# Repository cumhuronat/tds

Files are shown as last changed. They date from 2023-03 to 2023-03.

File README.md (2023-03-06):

# ESPHome TDS Sensor 
This is a tds sensor based on esp32-pico-d4 to be used for analyzing the status of a water purifier filters.
## Features

 - Powered by esphome
 - AC current generator to prevent polorization
 - OLED screen
 - Production ready
 - ADS1115 for precise voltage readings.
 - Temperature sensor for accurate tds calculation
 - 2.4GHZ PCB Antenna

## Pictures

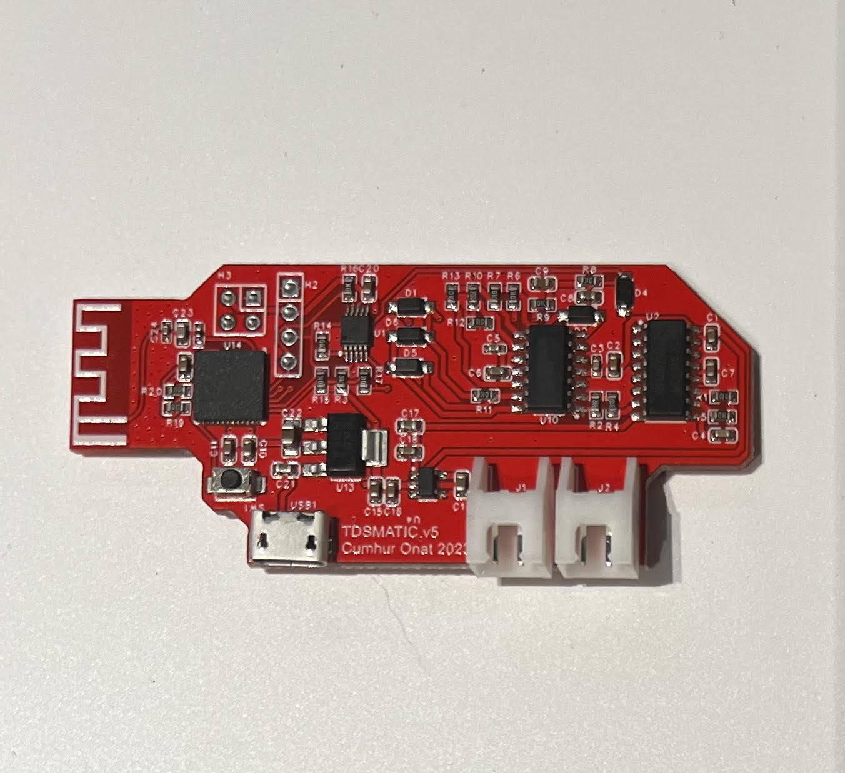
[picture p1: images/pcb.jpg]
pcb


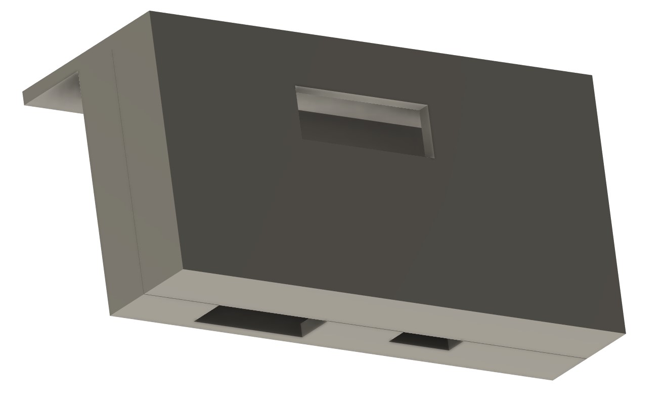
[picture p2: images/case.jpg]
case


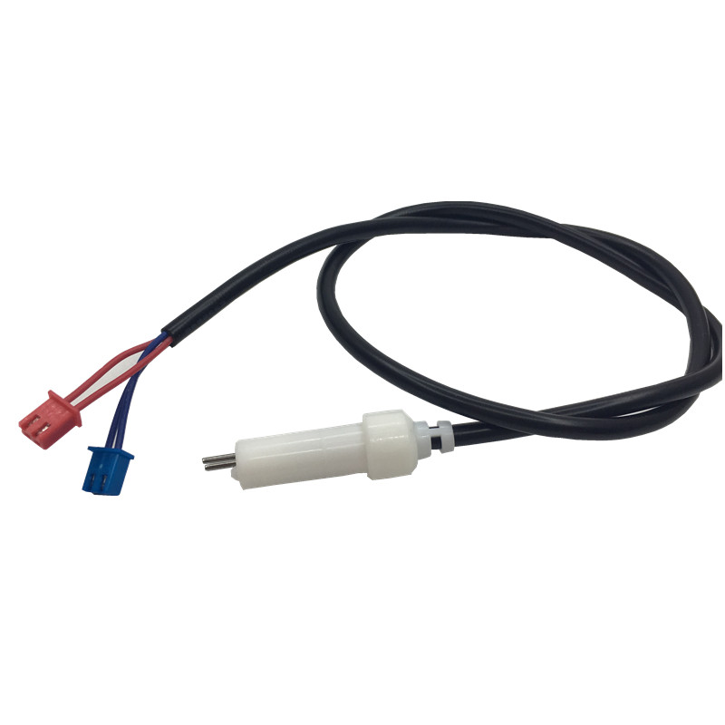
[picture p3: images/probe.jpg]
probe


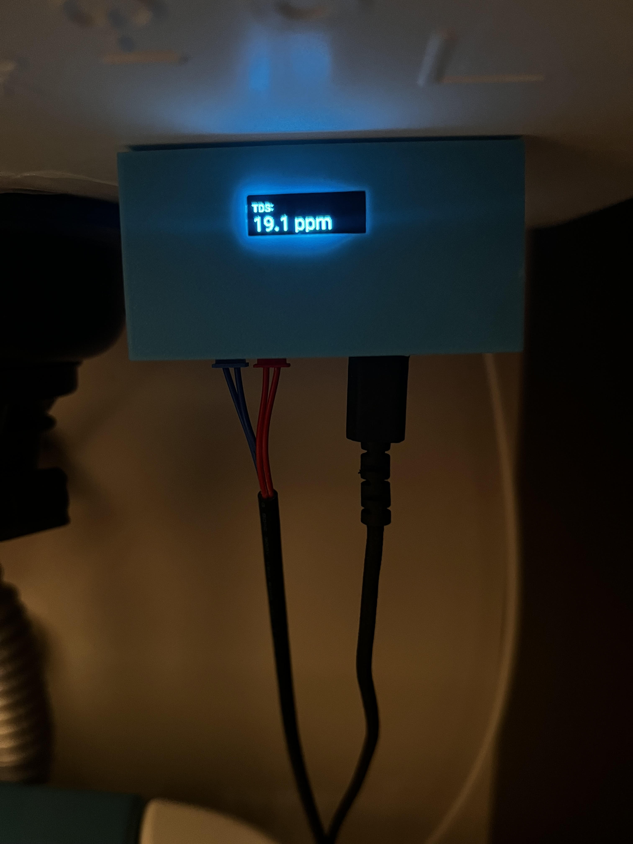
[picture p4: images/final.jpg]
final


## Notes

The pcb doesn't include a usb-ttl module hence you will need an external programmer like USB - TTL UART CP2102 or similar. H2 Header has the necessary pins for this purpose (3V3 GND RX TX).

You will need to order a probe with NTC 10k + electrodes. I've used:
https://www.aliexpress.com/item/1005004315383393.html

Part of the schmatic design is based on:
https://wiki.dfrobot.com/Gravity__Analog_TDS_Sensor___Meter_For_Arduino_SKU__SEN0244

The pcb includes headers for an 128x32 oled screen. I've used the following screen but you can use any oled screen with the same pinout.
https://www.aliexpress.com/item/1005004900370420.html

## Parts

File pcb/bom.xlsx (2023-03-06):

No. | Quantity | Comment | Designator | Footprint | Value | Manufacturer Part | Manufacturer | Supplier Part | Supplier
1 | 8 | 100nF | C1,C2,C6,C7,C11,C12,C16,C18 | C0603 | 100nF | CC0603KRX7R9BB104 | YAGEO(国巨) | C14663 | LCSC
2 | 2 | 4.7uF | C3,C5 | C0402 | 4.7uF | CL05A475MP5NRNC | SAMSUNG(三星) | C23733 | LCSC
3 | 1 | 1nF | C4 | C0603 | 1nF | CL10B102KB8NNNC | SAMSUNG(三星) | C1588 | LCSC
4 | 3 | 1uF | C8,C9,C20 | C0603 | 1uF | CL10A105KB8NNNC | SAMSUNG(三星) | C15849 | LCSC
5 | 5 | 10uF | C10,C14,C15,C17,C21 | C0603 | 10uF | CL10A106KP8NNNC | SAMSUNG(三星) | C19702 | LCSC
6 | 1 | 47uF | C22 | C0805 | 47uF | CL21A476MQYNNNE | SAMSUNG(三星) | C16780 | LCSC
7 | 1 | 4.7pF | C23 | C0603 | 4.7pF | 0603CG4R7C500NT | FH(风华) | C1669 | LCSC
8 | 1 | 2.7pF | C24 | C0402 | 2.7pF | 0402CG2R7C500NT | FH(风华) | C1561 | LCSC
9 | 4 | 1N4148W | D1,D2,D5,D6 | SOD-123F_L2.7-W1.6-LS3.8-RD |  | 1N4148W | ST(先科) | C81598 | LCSC
10 | 1 | 1N5819W | D4 | SOD-123_L2.8-W1.8-LS3.7-RD |  | 1N5819W | TWGMC(台湾迪嘉) | C727115 | LCSC
11 | 2 | S2B-XH-A-1(LF)(SN) | J1,J2 | CONN-TH_S2B-XH-A-1-LF-SN |  | S2B-XH-A-1(LF)(SN) | JST | C163035 | LCSC
12 | 1 | 1.6nH | L1 | L0402-RD | 1.6nH | LQG15HN1N6S02D | muRata(村田) | C435417 | LCSC
13 | 2 | 100kΩ | R1,R4 | R0603 | 100kΩ | 0603WAF1003T5E | UNI-ROYAL(厚声) | C25803 | LCSC
14 | 1 | 6.8kΩ | R2 | R0603 | 6.8kΩ | 0603WAF6801T5E | UNI-ROYAL(厚声) | C23212 | LCSC
15 | 13 | 10kΩ | R3,R5,R6,R7,R8,R9,R11,R13,R14,R15,R16,R17,R19 | R0603 | 10kΩ | 0603WAF1002T5E | UNI-ROYAL(厚声) | C25804 | LCSC
16 | 1 | 5.6kΩ | R10 | R0603 | 5.6kΩ | 0603WAF5601T5E | UNI-ROYAL(厚声) | C23189 | LCSC
17 | 1 | 0603WAF1004T5E | R12 | R0603 |  | 0603WAF1004T5E | UNI-ROYAL(厚声) | C22935 | LCSC
18 | 1 | SKRKAHE020 | SW1 | SW-SMD_L3.9-W2.9-LS4.8 |  | SKRKAHE020 | ALPSALPINE(阿尔卑斯阿尔派) | C202388 | LCSC
19 | 1 | CD4060BM | U2 | SOP-16_L9.9-W3.9-P1.27-LS6.1-BL |  | CD4060BM | TI(德州仪器) | C555139 | LCSC
20 | 1 | TPS60401DBVR | U4 | SOT-23-5_L3.0-W1.7-P0.95-LS2.8-BR |  | TPS60401DBVR | TI(德州仪器) | C29006 | LCSC
21 | 1 | LMV324IDR | U10 | SOIC-14_L8.7-W3.9-P1.27-LS6.0-BL |  | LMV324IDR | TI(德州仪器) | C7974 | LCSC
22 | 1 | ADS1115IDGSR | U11 | MSOP-10_L3.0-W3.0-P0.50-LS5.0-BL |  | ADS1115IDGSR | TI(德州仪器) | C37593 | LCSC
23 | 1 | LM1117MP-3.3/TR | U13 | SOT-223-3_L6.5-W3.4-P2.30-LS7.0-BR |  | LM1117MP-3.3/TR | HGSEMI(华冠) | C498153 | LCSC
24 | 1 | ESP32-PICO-D4 | U14 | LGA-48_L7.0-W7.0-P0.50-BL-EP5.4 |  | ESP32-PICO-D4 | ESPRESSIF(乐鑫) | C193707 | LCSC
25 | 1 | U254-051T-4BHJ25-F2S | USB1 | MICRO-USB-SMD_U254-051T-4BHJ25-F2S |  | U254-051T-4BHJ25-F2S | XKB Connectivity(中国星坤) | C381143 | LCSC

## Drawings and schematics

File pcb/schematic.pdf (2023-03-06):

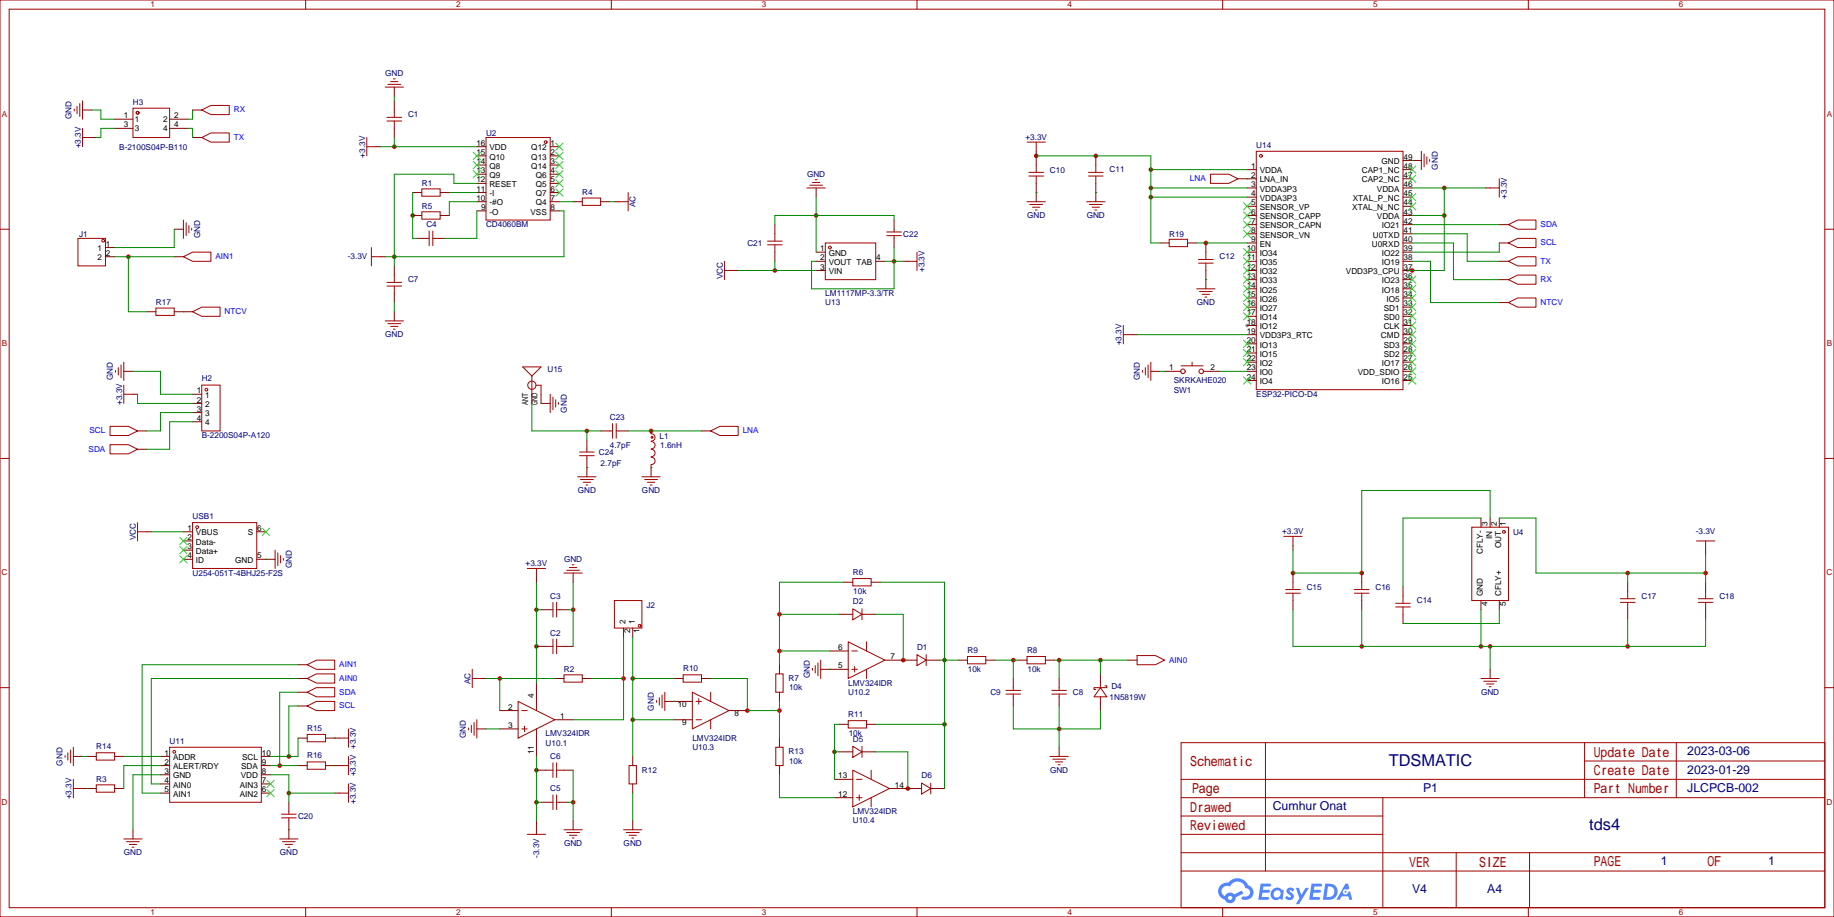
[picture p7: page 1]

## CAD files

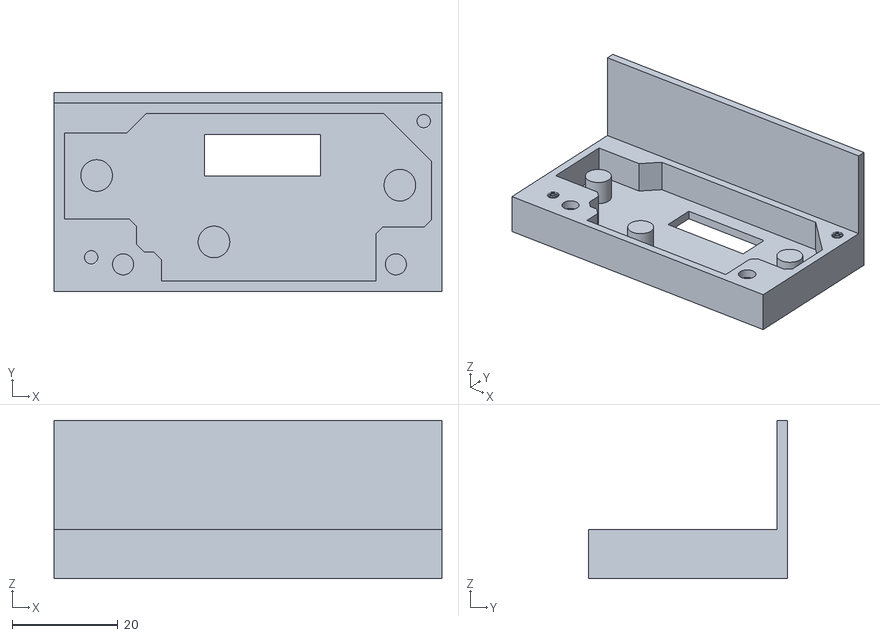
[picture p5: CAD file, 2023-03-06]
case/base.stl
73.5 x 37.7 x 30.0

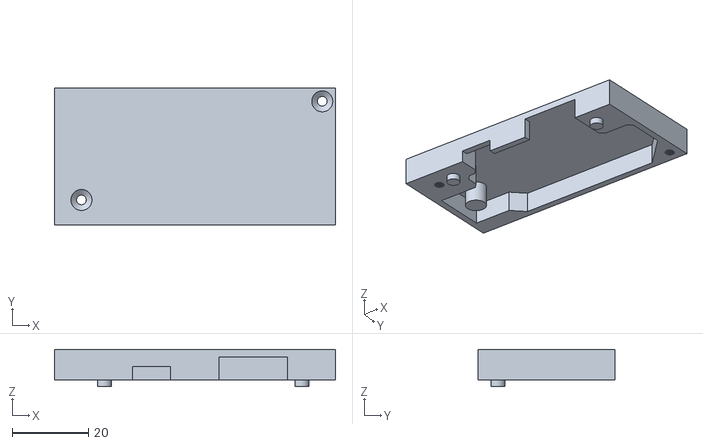
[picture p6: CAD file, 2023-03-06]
case/cap.stl
73.5 x 35.7 x 9.80
